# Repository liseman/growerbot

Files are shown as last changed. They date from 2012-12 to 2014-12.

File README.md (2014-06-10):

# Growerbot

Welcome to the Growerbot github repository. The growerbot is a social gardening assistant, more details at [growerbot.com](http://www.growerbot.com/)

## Arduino source 

To use the Arduino source you'll need those three libraries :

* [Time Library](http://www.arduino.cc/playground/uploads/Code/Time.zip)
* [Adafruits Lux sensor library](https://github.com/adafruit/TSL2561-Arduino-Library)
* [Adafruits DHT sensor library](https://github.com/adafruit/DHT-sensor-library)

Download them and put them into the libraries folder of your Aduino IDE installation.

To install Arduino IDE please go to : [http://arduino.cc/en/Main/Software](http://arduino.cc/en/Main/Software)

To upload the program into the Growerbot please follow the instruction on the fifth video of the [assembly videos](http://www.growerbot.com/2013/02/03/growerbot-kit-assembly-videos/).

### Linux Users

If you have installed Arduino IDE via an installer (i.e. apt-get) note that your library may be in your home folder at ~/sketchbook/libraries (Tested only with Ubuntu).
Also if you have problems compiling the Time library and it's the Time/DateString.cpp file that cause the problem you can remove all the "PROGMEM" keywords to make it compile without problems.

## Electric Imp Source

Those file are samples to use with the Electrc Imp SD card. Please refer to the Readme file into the folder for more help.

## PCBs

Those are the schematics and board design to build a Growerbot, you can also buy a kit at [www.growerbot.com/buy/](http://www.growerbot.com/buy/).

To learn what you need and how to build your Growerbot please watch the assembly videos at [www.growerbot.com/blog/](http://www.growerbot.com/2013/02/03/growerbot-kit-assembly-videos/)

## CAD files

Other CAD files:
enclosure models/diffuser75.ipt
enclosure models/screwflare74.ipt
enclosure models/tipthick1024.ipt

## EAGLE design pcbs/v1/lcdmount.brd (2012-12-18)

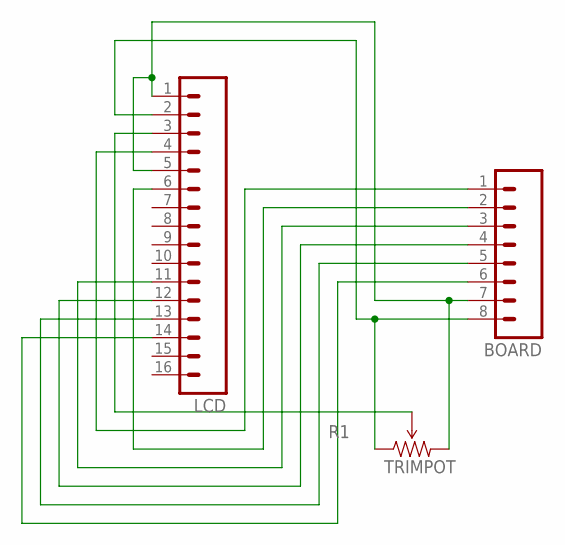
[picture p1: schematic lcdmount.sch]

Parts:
BOARD: M081X08; 1X08
LCD: M16PTH; 1X16
R1: TRIMPOT; 3362U-2

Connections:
unnamed: BOARD.7, LCD.1, LCD.5, R1.3 (CW)
unnamed: BOARD.8, LCD.2, R1.1 (CCW)
unnamed: LCD.3, R1.2 (WIPER)
unnamed: BOARD.1, LCD.4
unnamed: BOARD.3, LCD.11
unnamed: BOARD.2, LCD.6
unnamed: BOARD.4, LCD.12
unnamed: BOARD.5, LCD.13
unnamed: BOARD.6, LCD.14

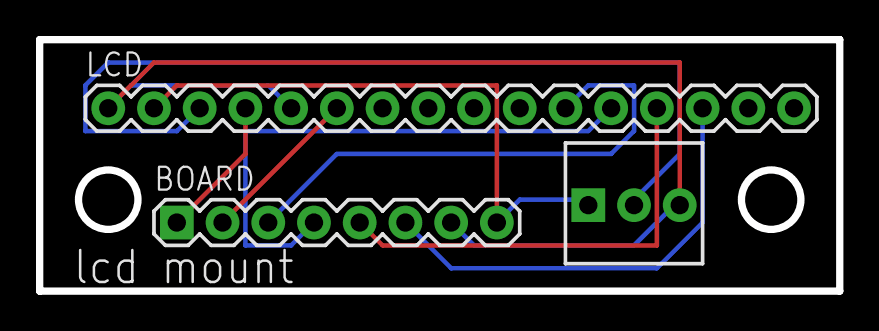
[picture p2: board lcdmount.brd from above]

Board: 2 copper layers, 44.5 x 14.0 mm, 3 parts (0 on the bottom side), 9 nets.

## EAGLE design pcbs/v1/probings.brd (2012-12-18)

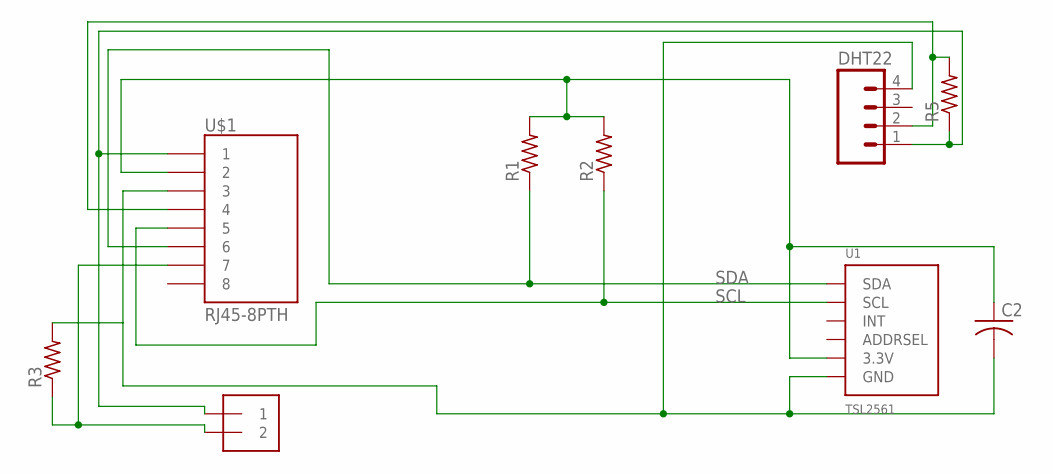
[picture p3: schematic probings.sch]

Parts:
C2: C-US025-024X044; C025-024X044
DHT22: M04PTH; 1X04
J1: 1X2-3.5MM
R1, R2, R3, R5: R-US_0204/7; 0204/7
U1: TSL2561; TSL2561_FN
U$1: RJ45-8PTH; RJ45-8

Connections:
unnamed: C2.1, R1.2, R2.2, U1.VDD (3.3V), U$1.2
unnamed: C2.2, DHT22.4, R3.2, U1.VSS (GND), U$1.3
unnamed: DHT22.1, J1.1, R5.1, U$1.1
unnamed: DHT22.2, R5.2, U$1.4
unnamed: J1.2, R3.1, U$1.7
SCL: R2.1, U1.CLK (SCL), U$1.5
SDA: R1.1, U1.DATA (SDA), U$1.6

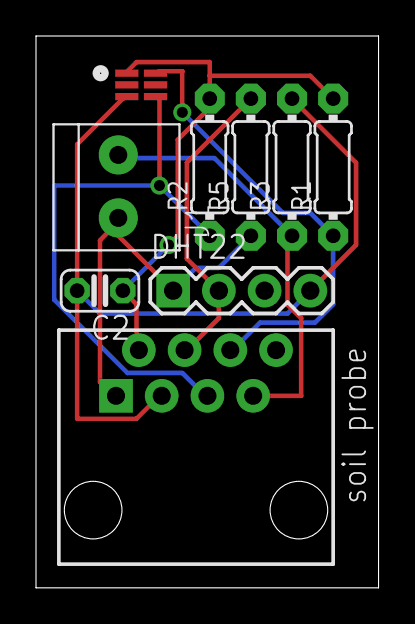
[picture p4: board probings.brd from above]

Board: 2 copper layers, 19.0 x 30.7 mm, 9 parts (0 on the bottom side), 7 nets.

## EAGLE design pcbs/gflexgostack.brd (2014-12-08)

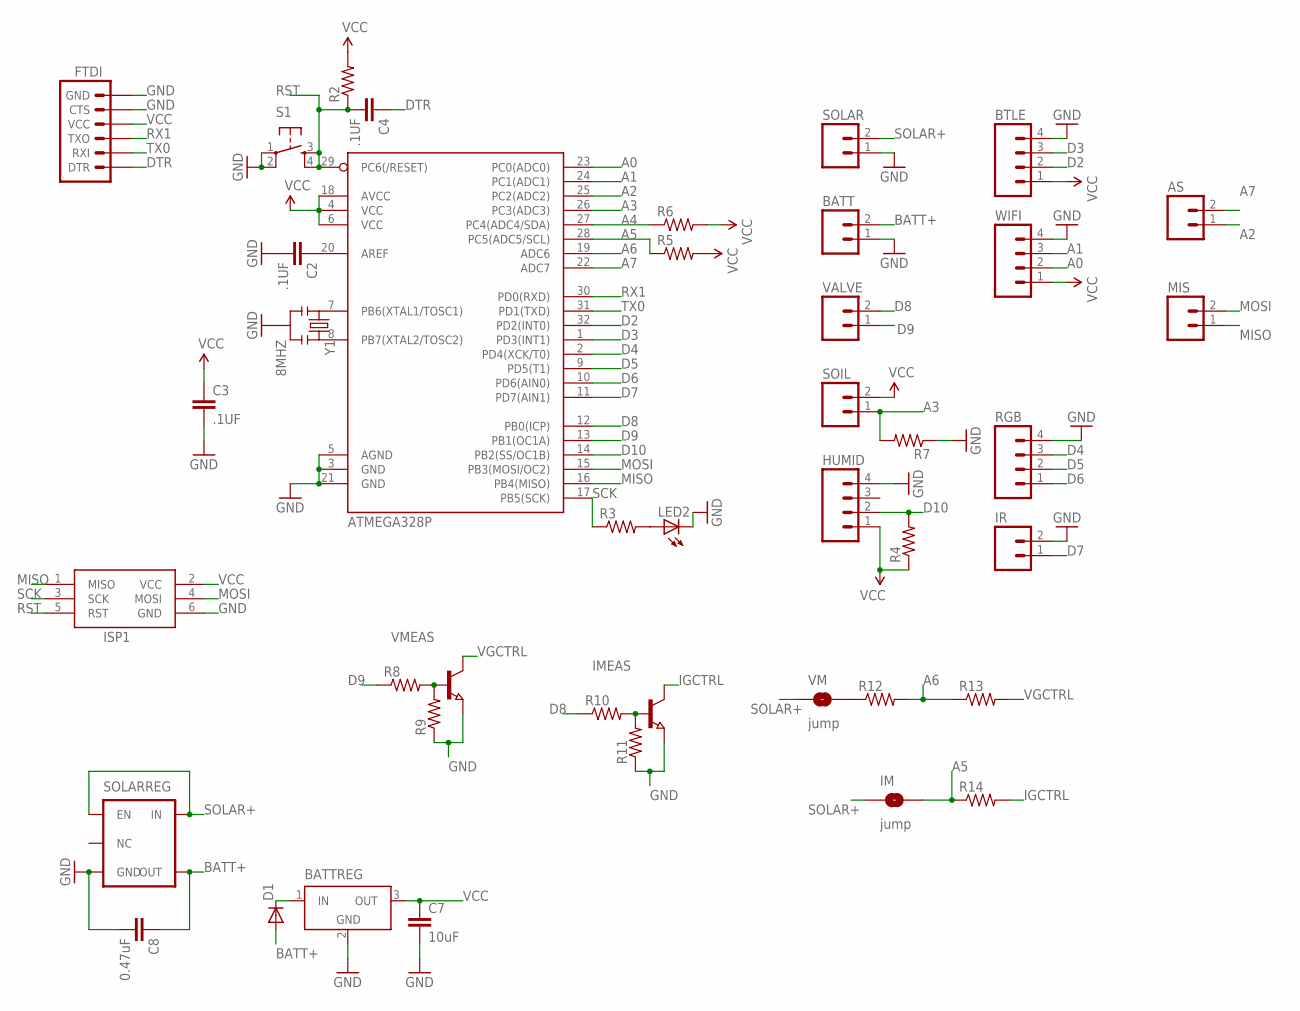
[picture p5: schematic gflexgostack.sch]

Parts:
AS: M02PTH; 1X02; DIGI PPTC021LFBN-RC
ATMEGA328P: ATMEGA168; TQFP32-08; DIGI ATMEGA328P-AU
BATT: M02PTH; 1X02; DIGI PPTC021LFBN-RC
BATTREG: LT1129CST5; SOT223; MPN LT1129CST-3.3#PBF-ND; DIGI MCP1826S-3302E/DB
BTLE: M04PTH; 1X04; DIGI PPTC041LFBN-RC
C2, C3, C4: .1UF; 0402-CAP; DIGI GRM155R71C104KA88D
C7: 10uF; 0402-CAP; DIGI AMK105CBJ106MV-F
C8: 0.47uF; 0402-CAP; DIGI GRM155R61A474KE15D
D1: DIODESMA; SMA-DIODE; DIGI B340A-13-F
FTDI: ARDUINO_SERIAL_PROGRAMPTH; 1X06; DIGI PPTC061LFBN-RC
HUMID: M04PTH; 1X04; DIGI PPTC041LFBN-RC
IM: jump; SJ_2S-TRACE
IMEAS: NPN-TRANSISTOR_SOT23; SOT23
IR: M02PTH; 1X02; DIGI PPTC021LFBN-RC
ISP1: AVRISP-6; AVRISP; DIGI 961206-6404-AR
LED2: LED0603; LED-0603; DIGI TLMG1100-GS08
MIS: M02PTH; 1X02; DIGI PPTC021LFBN-RC
R2, R4, R5, R6, R7: RESISTOR0603-RES; 0603-RES; DIGI ERJ-3GEYJ103V
R3: RESISTOR0603-RES; 0603-RES; DIGI ERJ-3GEYJ331V
R8, R10: RESISTOR0603-RES; 0603-RES; DIGI ERJ-3GEYJ431V
R9, R11: RESISTOR0603-RES; 0603-RES; DIGI ERJ-3GEYJ432V
R12: RESISTOR0603-RES; 0603-RES; DIGI ERJ-3GEYJ202V
R13: RESISTOR0603-RES; 0603-RES; DIGI ERJ-3GEYJ102V
R14: RESISTOR0603-RES; 0603-RES; DIGI ERJ-3RSJR10V
RGB: M04PTH; 1X04; DIGI PPTC041LFBN-RC
S1: TAC_SWITCHSMD; TACTILE_SWITCH_SMD; DIGI RS-187R05A2-DS MT RT
SOIL: M02PTH; 1X02; DIGI PPTC021LFBN-RC
SOLAR: M02PTH; 1X02; DIGI PPTC021LFBN-RC
SOLARREG: V_REG_MIC52195V; SOT23-5; DIGI MIC5213-5.0YC5 TR
VALVE: M02PTH; 1X02; DIGI PPTC021LFBN-RC
VM: jump; SJ_2S-TRACE
VMEAS: NPN-TRANSISTOR_SOT23; SOT23
WIFI: M04PTH; 1X04; DIGI PPTC041LFBN-RC
Y1: 8MHZ; RESONATOR-SMD; DIGI PRQV8.00CR5010Y000

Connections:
A0: ATMEGA328P.23 (PC0(ADC0)), WIFI.2
A1: ATMEGA328P.24 (PC1(ADC1)), WIFI.3
A2: AS.1, ATMEGA328P.25 (PC2(ADC2))
A3: ATMEGA328P.26 (PC3(ADC3)), R7.2, SOIL.1
A4: ATMEGA328P.27 (PC4(ADC4/SDA)), R6.1
A5: ATMEGA328P.28 (PC5(ADC5/SCL)), IM.2, R5.1, R14.1
A6: ATMEGA328P.19 (ADC6), R12.2, R13.1
A7: AS.2, ATMEGA328P.22 (ADC7)
BATT+: BATT.2, C8.1, D1.A, SOLARREG.4 (OUT)
D2: ATMEGA328P.32 (PD2(INT0)), BTLE.2
D3: ATMEGA328P.1 (PD3(INT1)), BTLE.3
D4: ATMEGA328P.2 (PD4(XCK/T0)), RGB.3
D5: ATMEGA328P.9 (PD5(T1)), RGB.2
D6: ATMEGA328P.10 (PD6(AIN0)), RGB.1
D7: ATMEGA328P.11 (PD7(AIN1)), IR.1
D8: ATMEGA328P.12 (PB0(ICP)), R10.1, VALVE.2
D9: ATMEGA328P.13 (PB1(OC1A)), R8.1, VALVE.1
D10: ATMEGA328P.14 (PB2(SS/OC1B)), HUMID.2, R4.2
DTR: C4.1, FTDI.1 (DTR)
GND: ATMEGA328P.3 (GND), ATMEGA328P.5 (AGND), ATMEGA328P.21 (GND), BATT.1, BATTREG.2 (GND), BATTREG.4 (GND), BTLE.4, C2.2, C3.2, C7.2, C8.2, FTDI.5 (CTS), FTDI.6 (GND), HUMID.4, IMEAS.2 (E), IR.2, ISP1.6 (GND), LED2.C, R7.1, R9.1, R11.1, RGB.4, S1.1, S1.2, SOLAR.1, SOLARREG.3 (GND), VMEAS.2 (E), WIFI.4, Y1.2
IGCTRL: IMEAS.3 (C), R14.2
MISO: ATMEGA328P.16 (PB4(MISO)), ISP1.1 (MISO), MIS.1
MOSI: ATMEGA328P.15 (PB3(MOSI/OC2)), ISP1.4 (MOSI), MIS.2
unnamed: ATMEGA328P.8 (PB7(XTAL2/TOSC2)), Y1.3
unnamed: ATMEGA328P.7 (PB6(XTAL1/TOSC1)), Y1.1
unnamed: R8.2, R9.2, VMEAS.1 (B)
unnamed: ATMEGA328P.20 (AREF), C2.1
unnamed: LED2.A, R3.2
unnamed: IMEAS.1 (B), R10.2, R11.2
unnamed: R12.1, VM.2
unnamed: BATTREG.1 (IN), D1.C
RST: ATMEGA328P.29 (PC6(/RESET)), C4.2, ISP1.5 (RST), R2.1, S1.3, S1.4
RX1: ATMEGA328P.30 (PD0(RXD)), FTDI.3 (TXO)
SCK: ATMEGA328P.17 (PB5(SCK)), ISP1.3 (SCK), R3.1
SOLAR+: IM.1, SOLAR.2, SOLARREG.1 (EN), SOLARREG.5 (IN), VM.1
TX0: ATMEGA328P.31 (PD1(TXD)), FTDI.2 (RXI)
VCC: ATMEGA328P.4 (VCC), ATMEGA328P.6 (VCC), ATMEGA328P.18 (AVCC), BATTREG.3 (OUT), BTLE.1, C3.1, C7.1, FTDI.4 (VCC), HUMID.1, ISP1.2 (VCC), R2.2, R4.1, R5.2, R6.2, SOIL.2, WIFI.1
VGCTRL: R13.2, VMEAS.3 (C)

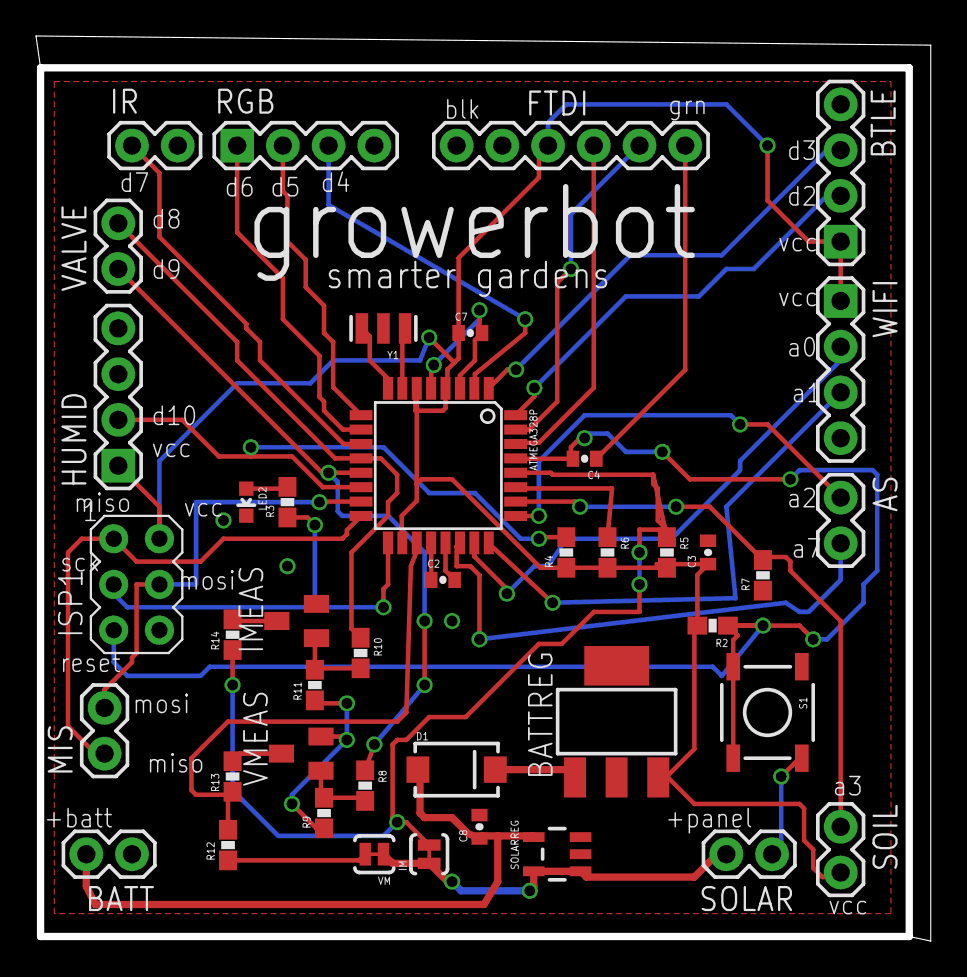
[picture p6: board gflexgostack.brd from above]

Board: 4 copper layers, 49.7 x 50.3 mm, 43 parts (0 on the bottom side), 38 nets.

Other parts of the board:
U$1: GLOGO

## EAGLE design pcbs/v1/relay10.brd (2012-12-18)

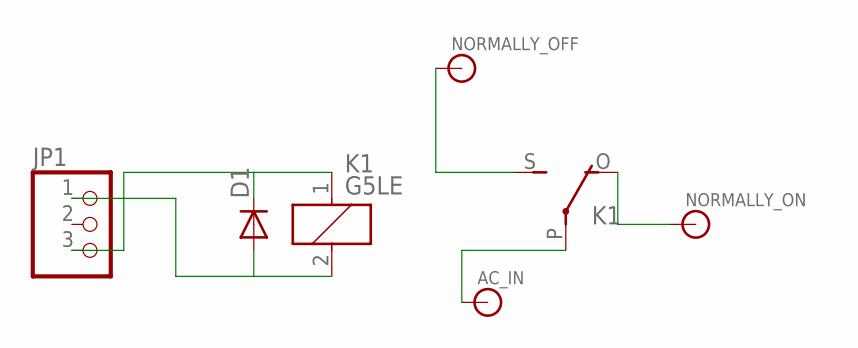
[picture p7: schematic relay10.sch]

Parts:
AC_IN: BANANA_CONN
D1: 1N4004; DO41-10
JP1: PINHD-1X3; 1X03
K1: G5LE
NORMALLY_OFF: BANANA_CONN
NORMALLY_ON: BANANA_CONN

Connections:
unnamed: D1.A, JP1.1, K1.2
unnamed: D1.C, JP1.3, K1.1
unnamed: K1.S, NORMALLY_OFF.P$1
unnamed: K1.O, NORMALLY_ON.P$1
unnamed: AC_IN.P$1, K1.P

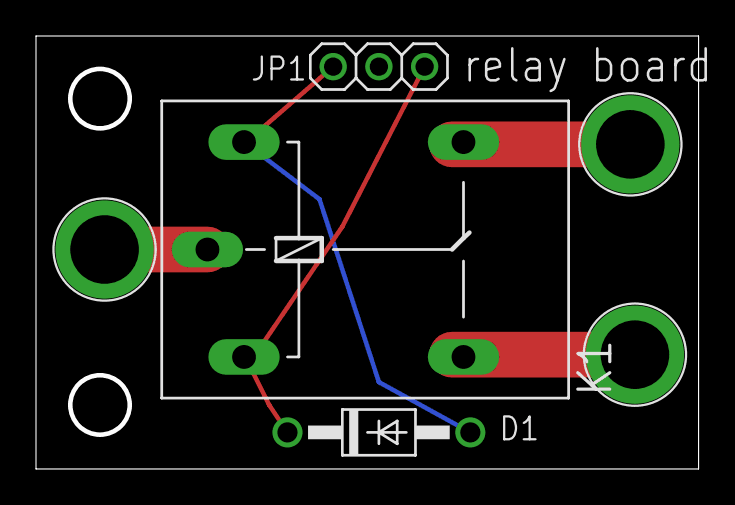
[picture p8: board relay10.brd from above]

Board: 2 copper layers, 36.8 x 24.1 mm, 6 parts (0 on the bottom side), 5 nets.

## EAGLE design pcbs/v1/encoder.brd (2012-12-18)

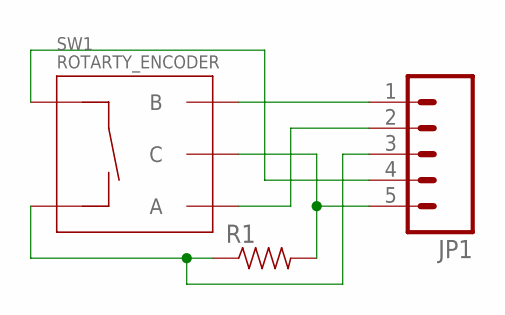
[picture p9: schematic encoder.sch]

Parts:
JP1: M05PTH; 1X05
R1: RESISTORPTH-1/4W; AXIAL-0.4
SW1: ROTARTY_ENCODER; ROTARY_ENC_PLAIN

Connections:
unnamed: JP1.1, SW1.B
unnamed: JP1.2, SW1.A
unnamed: JP1.5, R1.P$2 (2), SW1.C
unnamed: JP1.3, R1.P$1 (1), SW1.SW-
unnamed: JP1.4, SW1.SW+

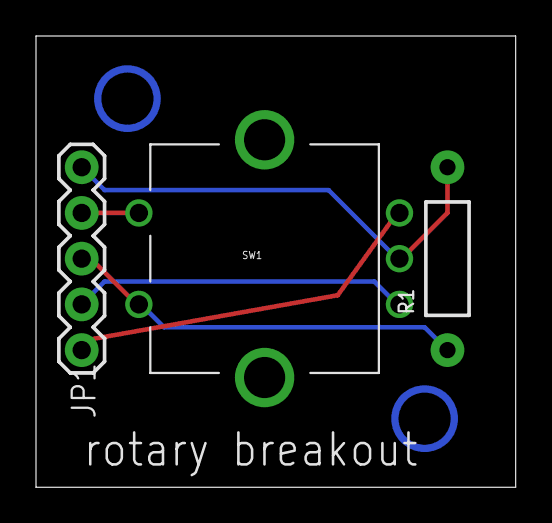
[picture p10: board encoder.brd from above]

Board: 2 copper layers, 26.6 x 25.1 mm, 3 parts (0 on the bottom side), 5 nets.

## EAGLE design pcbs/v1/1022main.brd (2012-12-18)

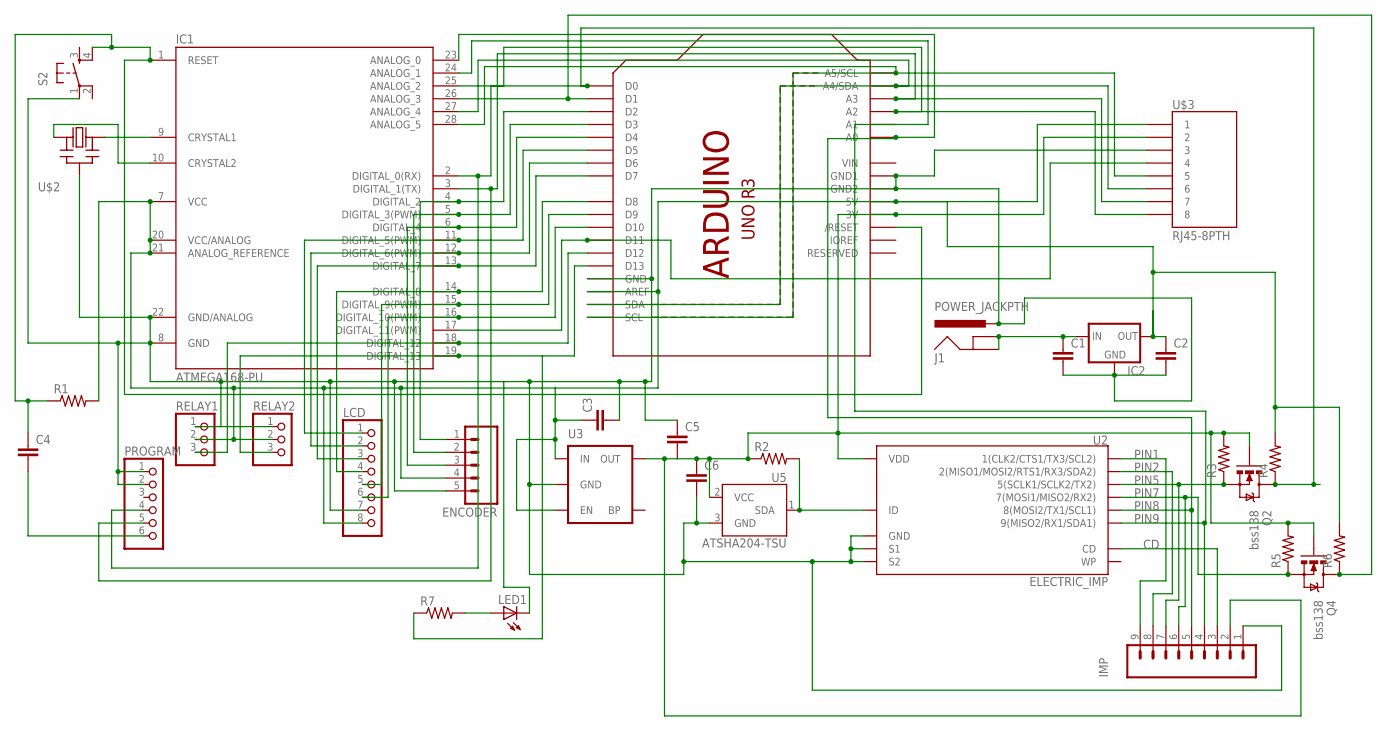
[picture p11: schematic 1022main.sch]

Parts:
C1, C2, C3, C4, C5, C6: CAPPTH; CAP-PTH-SMALL
ENCODER: M05PTH; 1X05
IC1: ATMEGA168-PU; DIL28-3
IC2: V_REG_78XX-TO-220; TO-220-ALT
IMP: M09; 1X09
J1: POWER_JACKPTH; POWER_JACK_PTH
LCD: PINHD-1X8CLEANBIG; 1X08-CLEANBIG
LED1: LED3MM
PROGRAM: PINHD-1X6; 1X06
Q2, Q4: bss138; SOT23-3
R1, R2, R3, R4, R5, R6, R7: R-US_0204/7; 0204/7
RELAY1, RELAY2: PINHD-1X3; 1X03
S2: TAC_SWITCHPTH; TACTILE-PTH
U1: ARDUINOR3-DIMENSION; ARDUINOR3
U2: ELECTRIC_IMP; SD_MMC_SOCKET
U3: V_REG_MIC52193.3V; SOT23-5
U5: ATSHA204-TSU; SOT23-3
U$2: CERMOSCILL-THM; CERM_OSC
U$3: RJ45-8PTH; RJ45-8

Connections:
3.3V: C5.2, C6.1, IMP.2, Q2.1 (G), Q4.1 (G), R2.1, R3.2, R5.2, U1.3V, U2.4 (VDD), U3.5 (OUT), U5.2 (VCC), U$3.2
CD: IMP.3, U2.CD
GND: C1.2, C2.2, C3.2, C5.1, C6.2, ENCODER.5, IC1.8 (GND), IC1.22 (GND/ANALOG), IC2.GND, IMP.1, J1.PWR, LCD.7, LED1.K (C), PROGRAM.1, PROGRAM.2, RELAY1.1, RELAY2.1, S2.1, U1.GND, U1.GND1, U1.GND2, U2.3 (GND), U2.S1, U2.S2, U3.2 (GND), U5.3 (GND), U$2.P$2 (GND), U$3.3
unnamed: IC1.19 (DIGITAL_13), R7.1, RELAY2.3, U1.D13
unnamed: IC1.18 (DIGITAL_12), RELAY1.3, U1.D12
unnamed: IC1.17 (DIGITAL_11(PWM)), U1.D11, U$3.4
unnamed: IC1.16 (DIGITAL_10(PWM)), LCD.6, U1.D10
unnamed: IC1.15 (DIGITAL_9(PWM)), LCD.5, U1.D9
unnamed: IC1.14 (DIGITAL_8), LCD.4, U1.D8
unnamed: IC1.13 (DIGITAL_7), LCD.3, U1.D7
unnamed: IC1.12 (DIGITAL_6(PWM)), LCD.2, U1.D6
unnamed: IC1.11 (DIGITAL_5(PWM)), LCD.1, U1.D5
unnamed: ENCODER.3, IC1.6 (DIGITAL_4), U1.D4
unnamed: ENCODER.2, IC1.5 (DIGITAL_3(PWM)), U1.D3
unnamed: ENCODER.1, IC1.4 (DIGITAL_2), U1.D2
unnamed: IC1.3 (DIGITAL_1(TX)), PROGRAM.5, Q4.3 (D), R6.1, U1.D1
unnamed: IC1.2 (DIGITAL_0(RX)), PROGRAM.4, Q2.3 (D), R4.1, U1.D0
unnamed: IC1.27 (ANALOG_4), U1.A4 (A4/SDA), U1.SDA, U$3.6
unnamed: IC1.28 (ANALOG_5), U1.A5 (A5/SCL), U1.SCL, U$3.5
unnamed: LED1.A, R7.2
unnamed: IC1.25 (ANALOG_2), U1.A2, U$3.8
unnamed: IC1.26 (ANALOG_3), U1.A3, U$3.7
unnamed: R2.2, U2.6 (ID), U5.1 (SDA)
unnamed: C1.1, IC2.IN, J1.GND, J1.GNDBREAK
unnamed: C4.2, PROGRAM.6
unnamed: IC1.9 (CRYSTAL1), U$2.P$3 (OUT)
unnamed: IC1.10 (CRYSTAL2), U$2.P$1 (IN)
unnamed: C2.1, C3.1, ENCODER.4, IC1.7 (VCC), IC1.20 (VCC/ANALOG), IC1.21 (ANALOG_REFERENCE), IC2.OUT, LCD.8, R1.2, R4.2, R6.2, RELAY1.2, RELAY2.2, U1.5V, U1.AREF, U3.1 (IN), U3.3 (EN), U$3.1
PIN1: IMP.9, U2.1 (1(CLK2/CTS1/TX3/SCL2))
PIN2: IMP.8, U2.2 (2(MISO1/MOSI2/RTS1/RX3/SDA2))
PIN5: IMP.7, Q2.2 (S), R3.1, U2.5 (5(SCLK1/SCLK2/TX2))
PIN7: IMP.6, Q4.2 (S), R5.1, U2.7 (7(MOSI1/MISO2/RX2))
PIN8: IC1.23 (ANALOG_0), IMP.5, U1.A0, U2.8 (8(MOSI2/TX1/SCL1))
PIN9: IC1.24 (ANALOG_1), IMP.4, U1.A1, U2.9 (9(MISO2/RX1/SDA1))
RELAY1: C4.1, IC1.1 (RESET), R1.1, S2.4, U1.RESET (/RESET)
VIN: U1.VIN

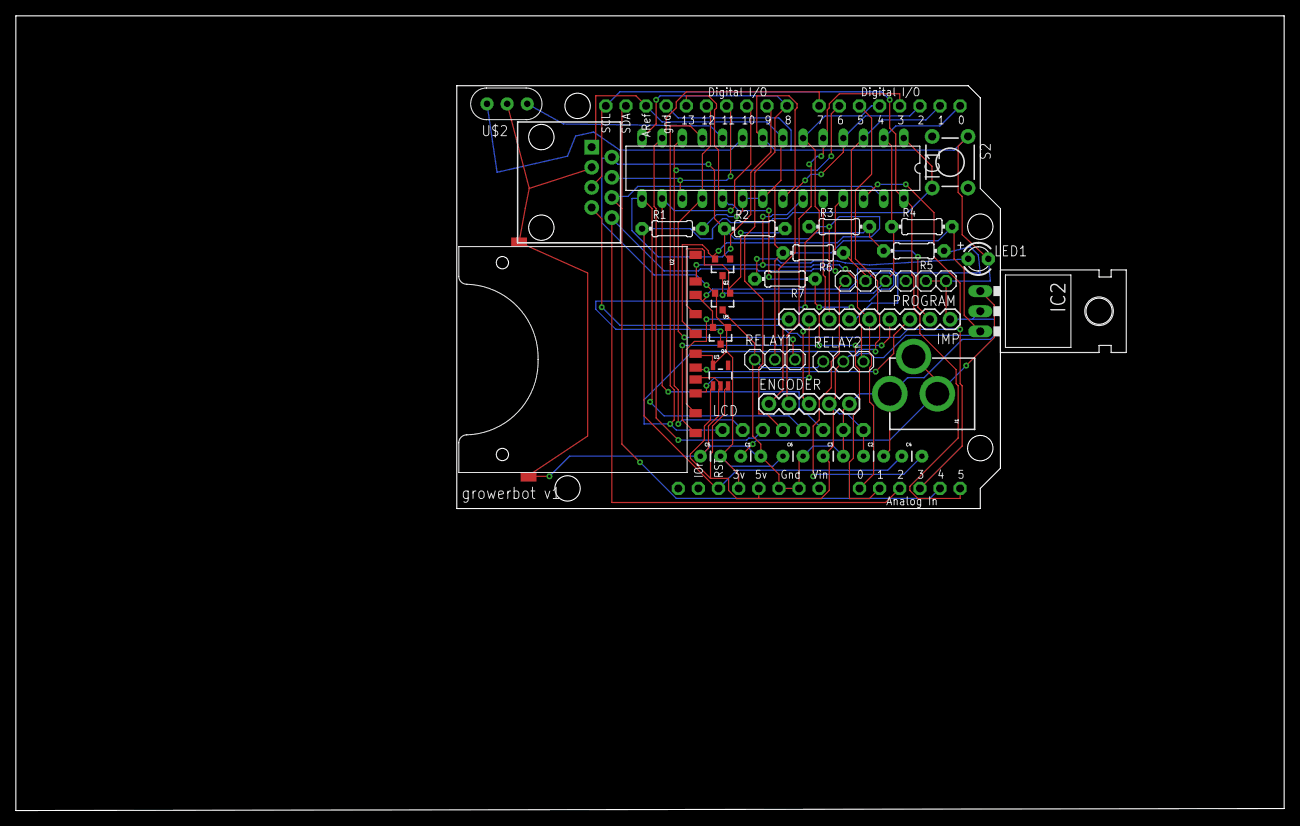
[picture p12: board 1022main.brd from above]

Board: 2 copper layers, 160.0 x 100.3 mm, 32 parts (0 on the bottom side), 35 nets.

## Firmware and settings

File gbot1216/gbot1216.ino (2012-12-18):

//growerbot version 1.0
//thanks to sparkfun (pcb layout libraries), adafruit (tsl2561, dht libraries), and arduino (community support, libraries). please support them all!

//garden name and growth profile
String growName = "indoor vertical";
String sourceName = "D.H. Landreth";
String sourceVariety = "heirloom peppers";
String apName = "";
String urlName = "l1.growerbot.com";

//lcd
#include <LiquidCrystal.h>
// initialize the library with the numbers of the interface pins
LiquidCrystal lcd(5, 6, 7, 8, 9, 10);

//rotary encoder
int encoderPin1 = 2;
int encoderPin2 = 3;
volatile int lastEncoded = 0;
volatile long encoderValue = 0;
long lastEncoderValue = 0;
int lastMSB = 0;
int lastLSB = 0;
int buttonPin = 4;
bool buttonState = 0;
int menu = 0;
int menuSub = 0;
int pRotationIncrement = 25;
int nRotationIncrement = -25;
boolean menuChange = false;
boolean valueChange = false;
bool subMenu = 0;
float time = 0;
int debounce = 50;
bool previous = 0;

//light sensor
#include <Wire.h>
#include <TSL2561.h>
TSL2561 tsl(TSL2561_ADDR_FLOAT);
uint16_t ir, full, visible, luxOld, luxNew, lum;
//set target light level here
uint16_t luxGoal = 250;
//set target light proportion here
float lightProportionGoal = .7;
float lightProportion = 0;
//indicates current status of light. ? todo switch to just reading if relay pin is high or low?
bool lightOn = 0;
//mimimum and maximum amounts of time for light to turn on in seconds. only used if lightCycle = 1
bool lightCycle = 0;
int minLightCycleTime = 5;
int maxLightCycleTime = 600;
//minimum and maximum numbers of times for light to turn on per day. only used if lightDaily = 1
bool lightDaily = 0;
int minLightsDaily = 0;
int maxLightsDaily = 10;
//times light has been on today
int lightsToday = 0;
//seconds light is on
float timeLightOn = 0;
//seconds during which light level is at or above minimum lux
float timeBrightEnough = 0;
//number of seconds between turning lights off (makes sure we don't keep our assisted lighting on when it's bright enough naturally for the plants)
int lightCheckFrequency = 1200;

//temp, humidity sensor
#include <DHT.h>
#define DHTPIN 11
#define DHTTYPE DHT22
DHT dht(DHTPIN, DHTTYPE);
float humidOld, humidNew, tempOld, tempNew;

//moisture probes
int moisturePin = 3;
int moistOld = 0, moistNew = 0;
//set target moisture level here
int moistGoal = 200;
bool pumpOn = 0;
//mimimum and maximum amounts of time for pump to turn on in seconds
int minPumpCycleTime = 5;
int maxPumpCycleTime = 600;
//length of current pump cycle
int currentCycleTime = 0;
//minimum and maximum numbers of times for pump to turn on per day
int minPumpsDaily = 0;
int maxPumpsDaily = 10;
//number of times pump has run today
int pumpsToday = 0;
//seconds pump is on
long timePumpOn = 0;
//total time elapsed
float timeTotal = 0;
float timeNew = 0;
float timeOld = 0;
int daysLeft = 30, daysElapsed = 0;

//relays
int relayWater = 12;
int relayLight = 13;

//imp 
#include <SoftwareSerial.h>
SoftwareSerial softSerial(14,15); //rx, tx

//timers
#include <Time.h>
#include <TimeAlarms.h>

//variables for input from server
boolean stringComplete = false;
String inputString = "";

//array to hold all variables we care about passing between cloud and garden
//String variablesPassing[] = {relayWater + humidNew + profileName};
String toSend;

//long resetInterval = 

void setup()
{
  inputString.reserve(200);
  
  //lcd
  lcd.begin(16, 2); 
  lcd.print("growerbot v1.0");
  
  //rotary
  pinMode(encoderPin1, INPUT);
  pinMode(encoderPin2, INPUT);
  pinMode(buttonPin, INPUT);
  digitalWrite(encoderPin1, HIGH);
  digitalWrite(encoderPin2, HIGH);
  attachInterrupt(0, updateEncoder, CHANGE);
  attachInterrupt(1, updateEncoder, CHANGE);
  
  //light
  tsl.setGain(TSL2561_GAIN_16X);
  tsl.setTiming(TSL2561_INTEGRATIONTIME_13MS);
  
  //temp
  pinMode(DHTPIN, INPUT);
  dht.begin();
  
  //relays
  pinMode(relayWater, OUTPUT);
  pinMode(relayLight, OUTPUT);
  digitalWrite(relayWater, LOW);
  digitalWrite(relayLight, LOW);
  
  //define how many seconds to pass between sensor, relay checks, send data, and receive settings
  int sensorCheckFrequency = 1;
  int relayCheckFrequency = 5;
  int dataSendFrequency = 60;
  int settingReceiveFrequency = 3600;
  
  //timers
  //read sensors every 1 second
  Alarm.timerRepeat(sensorCheckFrequency, checkSensors);
  //check if relays should be on every 5 seconds, watering or lighting as necessary
  Alarm.timerRepeat(relayCheckFrequency, relayCheck);
  //send data to server every minute
  Alarm.timerRepeat(dataSendFrequency, sendData);
  //blink lights this frequency, to make sure we're not leaving them on when natural light is sufficient
  Alarm.timerRepeat(lightCheckFrequency, lightCheck);
  //todo: reset daily stuff, proportions every day
  //Alarm.timerRepeat(resetInterval, resetStuff);
  //serial
  Serial.begin(9600);
  softSerial.begin(2400);
}

void loop()
{
  //checks state of scheduled events, as per http://answers.oreilly.com/topic/2704-how-to-create-an-arduino-alarm-that-calls-a-function/ 
  Alarm.delay(1);
  encodeDisplay();
  //check for input on softSerial
  softSerialCheck();
}

void encodeDisplay()
{
  //update display based on menu rotation
  if (encoderValue > pRotationIncrement)
  {
    if ( subMenu == 0) menu++;
    else menuSub++;
    encoderValue = 0;
    menuChange = true;
  }
  if (encoderValue < nRotationIncrement)
  {
    if ( subMenu == 0) menu--;
    else menuSub--;
    encoderValue = 0;
    menuChange = true;
  }
  
  //update lcd whenever sensor value or menu change
  if (subMenu == 0 && (menuChange == true || valueChange == true))
  {
    lcd.clear();
    lcd.setCursor(0,0);
    switch(menu) 
    {
    case -1:
      menu = 5;
      break;
    case 0:
    //grow menu
      lcd.print(growName);
      lcd.setCursor(0,1);
      lcd.print(daysLeft);
      lcd.print(" days left");
      break;
    case 1:
    //light menu
      lcd.print("light ");
      lcd.print(luxNew);
      lcd.print(" lux");
      lcd.setCursor(0,1);
      lcd.print("proportion ");
      lcd.print(lightProportion);
      break;
    case 2:
    //moisture menu
      lcd.print("moisture level");
      lcd.setCursor(0,1);
      lcd.print(moistNew);
      break;
    case 3:
    //temp/humidity
      lcd.print(tempNew);
      lcd.print(" Celsius");
      lcd.setCursor(0,1);
      lcd.print(humidNew);
      lcd.print("% humidity");
      break;
    case 4:
    //connection
      lcd.print("AP ");
      lcd.print(apName);
      lcd.setCursor(0,1);
      lcd.print(urlName);
      break;
    case 5:
      menu = 0;
      break;
    }
  }
  
  //update lcd whenever sensor value or submenu change
  if (subMenu == 1 && (menuChange == true || valueChange == true))
  {  
    lcd.clear();
    lcd.setCursor(0,0);
    //decide which submenu to show based on main menu
    switch(menu) 
    {
    case -1:
      menu = 5;
      break;
    //growMenu's submenus
    case 0:
      switch(menuSub)
      {
        case -1:
          menuSub = 1;
          break;
        case 0:
          lcd.print("planted ");
          lcd.print(daysElapsed);
          lcd.setCursor(0,1);
          lcd.print("days ago");        
          break;
        case 1: 
          lcd.print(sourceName);
          lcd.setCursor(0,1);
          lcd.print(sourceVariety);
          break;
        case 2:
          menuSub = 0;
          break;
      }
      break;
    //lightMenu's submenus
    case 1:
      switch(menuSub)
      {
        case -1:
          menuSub = 3;
          break;
        case 0:
          lcd.print("target ");
          lcd.print(luxGoal);
          lcd.print(" lux");
          lcd.setCursor(0,1);
          lcd.print("proportion ");
          lcd.print(lightProportionGoal);
          break;
        case 1: 
          lcd.print("infrared");
          lcd.setCursor(0,1);
          lcd.print(ir);
          break;
        case 2: 
          lcd.print("visible");
          lcd.setCursor(0,1);
          lcd.print(visible);          
          break;
        case 3: 
          lcd.print("lumens");
          lcd.print(lum);
          break;
        case 4: 
          menuSub = 0;
          break;
      }
      break;
    //moistMenu's submenus
    case 2:
      lcd.print("target level");
      lcd.setCursor(0,1);
      lcd.print(moistGoal);
      break;
    //tempMenu's submenus
    case 3:
      break;
    //connMenu's submenus
    case 4:  
      break;
    case 5: 
      menu = 0;
      break;
    }
  }
  
  //read button press. use debounce to adjust. thx to arduino.cc for some of code
  buttonState=digitalRead(buttonPin);
  if (buttonState == 1 && previous == 0 && millis() - time > debounce)
  {
    if (subMenu == 1) 
    {
      subMenu = 0;
      menuSub = 0;
    }
    else subMenu = 1;
    time = millis();
    menuChange == true;
  }
  previous = buttonState;
  menuChange = false;
  valueChange = false;
}

void softSerialCheck()
{
  while (softSerial.available())
  {
    char inChar = (char)softSerial.read();
    inputString += inChar; 
    //Serial.println(inputString);
    if (inChar == '\n')
    {
      stringComplete = true;
    }
  }

  if (stringComplete) 
  {
    Serial.println(inputString);
    //use light proportion setting if sent from imp cloud
    if (inputString.indexOf("L") > -1)
    {
      int start = inputString.indexOf("L") + 1; 
      int end = inputString.lastIndexOf("L");
      String lightSection = inputString.substring(start, end);
      char lightChar[] = "";
      lightSection.toCharArray(lightChar, sizeof(lightSection));
      lightProportionGoal = atof(lightChar);
    }
    //use light brightness setting if sent from imp cloud
    if (inputString.indexOf("B") > -1)
    {
      int start = inputString.indexOf("B") + 1; 
      int end = inputString.lastIndexOf("B");
      String luxSection = inputString.substring(start, end);
      char luxChar[] = "";
      luxSection.toCharArray(luxChar, sizeof(luxSection));
      luxGoal = atoi(luxChar);
      Serial.println(luxGoal);
    }
    //use moisture setting if sent from imp cloud
    if (inputString.indexOf("M") > -1)
    {
      int start = inputString.indexOf("M") + 1; 
      int end = inputString.lastIndexOf("M");
      String moistSection = inputString.substring(start, end);
      char moistChar[] = "";
      moistSection.toCharArray(moistChar, sizeof(moistSection));
      moistGoal = atoi(moistChar);
    }
    //turn on light if Ll1 is received from imp cloud. note that normal cycling still applies: may go off moments later
    if (inputString.indexOf("Ll1") > -1) digitalWrite(relayLight, HIGH);
    //turn on pump if Pp1 is received from imp cloud. note that normal cycling still applies: may go off moments later
    if (inputString.indexOf("Pp1") > -1) digitalWrite(relayWater, HIGH);
    inputString = "";
    stringComplete = false; 
  }
}

//read light, temperature, humidity, and moisture from sensors
void checkSensors()
{
  light();
  temphum();
  moist();  
  //check if any values have changed. if so, update display.
  if (luxOld != luxNew || moistOld != moistNew || humidOld != humidNew || tempOld != tempNew) valueChange = true;
}

void light()
{
  luxOld = luxNew;
  lum = tsl.getFullLuminosity();
  ir = lum >> 16;
  full = lum & 0xFFFF;
  visible = full - ir;
  luxNew = tsl.calculateLux(full, ir);
}

void temphum()
{
  humidOld = humidNew;
  tempOld = tempNew;
  humidNew = dht.readHumidity();
  tempNew = dht.readTemperature();
}

void moist()
{
  moistOld = moistNew;
  moistNew = analogRead(moisturePin);
  //Serial.print("moisture level ");
  //Serial.println(moistNew);
}

//read encoder turning
void updateEncoder()
{
  int MSB = digitalRead(encoderPin1); //MSB = most significant bit
  int LSB = digitalRead(encoderPin2); //LSB = least significant bit
  int encoded = (MSB << 1) |LSB; //converting the 2 pin value to single number
  int sum  = (lastEncoded << 2) | encoded; //adding it to the previous encoded value
  if(sum == 0b1101 || sum == 0b0100 || sum == 0b0010 || sum == 0b1011) encoderValue ++;
  if(sum == 0b1110 || sum == 0b0111 || sum == 0b0001 || sum == 0b1000) encoderValue --;
  lastEncoded = encoded; //store this value for next time
}

//check whether a relay needs turned on
void relayCheck()
{
//update time elapsed in total
timeTotal = now();
timeNew = timeTotal - timeOld;
//Serial.print(timeNew);
//Serial.print(now());

//check water; turn on & increment time if below optimal level 
if (moistNew < moistGoal)
{
  Serial.println("turning water on");
  digitalWrite(relayWater, HIGH);
  //todo: off by 5 seconds on this and light; fix?
  timePumpOn = timePumpOn + timeNew;
}
else digitalWrite(relayWater, LOW);

//light
//if luxNew > luxGoal, add timeNew to timeBrightEnough
if (luxNew >= luxGoal)
{
  timeBrightEnough = timeBrightEnough + timeNew;
  //Serial.print("time counts");
  //Serial.println(timeBrightEnough);
  //add to timeLightOn if light is on
}
//calculate lightProportion
lightProportion = timeBrightEnough / timeTotal;

//turn on light if proportion < goal and luxNew < luxGoal
if (lightProportion < lightProportionGoal && luxNew < luxGoal)
{
  Serial.println("turning light on");
  digitalWrite(relayLight, HIGH);
  timeLightOn = timeLightOn + timeNew;
}
else digitalWrite(relayLight, LOW);

timeOld = now();
}

void sendData()
{
  toSend  = String("");
  char temp[10];
  dtostrf(tempNew,1,2,temp);
  char hum[10];
  dtostrf(humidNew,1,2,hum);
  toSend = String(toSend + "L" + luxNew + "L" + "M" + moistNew + "M" + "T" + temp + "T" + "H" + hum + "H");
  //Serial.println(toSend);
  Serial.print("sending");
  Serial.println(toSend);
  softSerial.print(toSend);
}

void lightCheck()
{
    digitalWrite(relayLight, LOW);
}

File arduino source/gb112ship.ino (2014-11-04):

 //sends data to server every 1.something minutes

//based on code from adafruit and sparkfun. pls support them!

//decide whether arduino should go to sleep 
bool sleep = true;


//dht
#include "DHT.h"
DHT dht;

//moisture
int moisturePin = 3;
int moistVal = 0;

//light
int lightPin = A0;
int lightVal = 0;

//imp
#include <SoftwareSerial.h>
#include <String.h>
SoftwareSerial mySerial(2, 3);

//sleep stuff
#include <avr/sleep.h>
#include <avr/power.h>
#include <avr/wdt.h>
volatile int f_wdt=1;

void setup(void)
{
  mySerial.begin(19200);
  
  Serial.begin(115200);
  
  //dht
  dht.setup(10); // data pin 2
  
  delay(1000); 
  
    //sleepstuff
  /*** Setup the WDT ***/
  
  /* Clear the reset flag. */
  MCUSR &= ~(1<<WDRF);
  
  /* In order to change WDE or the prescaler, we need to
   * set WDCE (This will allow updates for 4 clock cycles).
   */
  WDTCSR |= (1<<WDCE) | (1<<WDE);

  /* set new watchdog timeout prescaler value */
  WDTCSR = 1<<WDP0 | 1<<WDP3; /* 8.0 seconds */
  
  /* Enable the WD interrupt (note no reset). */
  WDTCSR |= _BV(WDIE);
  
  pinMode(A1, OUTPUT);
  pinMode(A2, OUTPUT);
  digitalWrite(A1, LOW);
  digitalWrite(A2, LOW);
}

void loop(void)
{
 
  Serial.println("good morning");
  
  //turn on pins for moisture and light sensor
  digitalWrite(A1, HIGH);
  digitalWrite(A2, HIGH);
  
  delay(2000);
  
  //delay(dht.getMinimumSamplingPeriod());
  float h = dht.getHumidity();
  float t = dht.getTemperature();
  //delay(1000);
  int temperature = (int) t;
  int humidity = (int) h;
  Serial.println(temperature);
  Serial.println(humidity);
  String temp = "|Temperature, " + (String)temperature + "~";
  Serial.println(temp);
  mySerial.println(temp);
  
  String humid = "|Humidity, " + (String)humidity + "~";
  Serial.println(humid);
  mySerial.println(humid);
  
  moistVal = analogRead(moisturePin);
  String moist = "|Moisture, " + (String)moistVal + "~";
  Serial.println(moist);
  mySerial.println(moist);
  
  //light
  int lightVal = analogRead(lightPin);
  Serial.println(lightVal);
  String light = "|Light, " + (String)lightVal + "~";
  Serial.println(light);
  mySerial.println(light);
  //delay(20);
  //delay(200);
  //turn off digital outputs to sensors. questionable if necessary.
  digitalWrite(A1, LOW);
  digitalWrite(A2, LOW);
  
  //delay(1000);
  
  if (sleep == true)
  {
  //~8 seconds each * 7 = 56.
  //sleepstuff
  f_wdt=0;
  enterSleep();
  //sleepstuff
  f_wdt=0;
  enterSleep();
  //sleepstuff
  f_wdt=0;
  enterSleep();
  //sleepstuff
  f_wdt=0;
  enterSleep();
  //sleepstuff
  f_wdt=0;
  enterSleep();
  //sleepstuff
  f_wdt=0;
  enterSleep();
  //sleepstuff
  f_wdt=0;
  enterSleep();
  }
}




/***************************************************
 *  Name:        ISR(WDT_vect)
 *
 *  Returns:     Nothing.
 *
 *  Parameters:  None.
 *
 *  Description: Watchdog Interrupt Service. This
 *               is executed when watchdog timed out.
 *
 ***************************************************/

ISR(WDT_vect)
{
  if (sleep == true)
  {
  if(f_wdt == 0)
  {
    f_wdt=1;
  }
  else
  {
    Serial.println("WDT Overrun!!!");
  }
  }
}

/***************************************************
 *  Name:        enterSleep
 *
 *  Returns:     Nothing.
 *
 *  Parameters:  None.
 *
 *  Description: Enters the arduino into sleep mode.
 *
 ***************************************************/
void enterSleep(void)
{
  Serial.println("goodnight");
  delay(100);
  set_sleep_mode(SLEEP_MODE_PWR_DOWN);   /* EDIT: could also use SLEEP_MODE_PWR_DOWN for lowest power consumption. */
  sleep_enable();
  
  /* Now enter sleep mode. */
  sleep_mode();
  
  /* The program will continue from here after the WDT timeout*/
  sleep_disable(); /* First thing to do is disable sleep. */
  
  /* Re-enable the peripherals. */
  power_all_enable();
}

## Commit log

2012-12-18 eagle source for kickstarter production boards
    [1022main.brd, 1022main.sch, encoder.brd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]
2013-01-06 fixed folder names, updated arduino code
    [1022main.brd, 1022main.sch, encoder.brd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]
2014-05-27 Ading demo for the new agent and device IDE on Electric Imp
2014-12-08 updating all to v1.5
    [1022main.brd, 1022main.sch, diffuser75.ipt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]

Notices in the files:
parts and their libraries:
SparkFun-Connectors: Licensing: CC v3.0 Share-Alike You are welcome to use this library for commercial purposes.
